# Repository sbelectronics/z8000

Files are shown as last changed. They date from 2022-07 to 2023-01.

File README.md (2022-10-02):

Scott's Z-8000 CP/M-8000 "clover computer"
http://www.smbaker.com/

Description

This is a set of boards that can be assembled to make Z8000 computer,
running the CP/M-8000 distribution. For a detailed writeup, see my
website at http://www.smbaker/com/

Prequisites

* z8kgcc
* cpmtools

Building

Run `make asm` and then `make rom`.

Ports

* 00-0F - SCC, serial I/O
* 10-1F - PIO, parallel I/O
* 20-2F - IDE, compactflash
* 30-3F - unused, optional second IDE
* 40-4F - floppy controller
* 50-53 - display board
* 58-59 - speech synthesizer
* 61-6F - TMS9918 (61 = DATA, 63=CMD, 65-ACR)

Acknowledgements:

* Digital Corporation, CP/M-8k Source Code
* 4sun5bu, Z8001 MB Project including BIOS and Monitor, https://github.com/4sun5bu/Z8001MB

License
* MIT, unless specified elsewhere

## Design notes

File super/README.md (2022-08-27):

# Supervisor board for Z8000
Scott Baker, www.smbaker.com

This directory supports a raspberry pi supervisor. The supervisor can be used
to peek and poke memory locations as well as to run a disk (called "superdisk").

Surprisingly, the C-extension version (supervisor_direct.py) in and of itself
wasn't much faster than the plain ordinary python version. What did really help
was two things: 1) snooping the data bus to look for a wakeup rather than
periodically reading a memory address, and 2) getting rid of as much i2c as
possible in favor of using data buffers.

Speeding up the i2c from 100KHz to 1.2MHz will make a large difference.

to increase i2c speed, edit /boot/config.txt
  dtparam=i2c_arm=on -->  dtparam=i2c_arm=on,i2c_arm_baudrate=1200000

make sure to run raspi-config and disable spi
  otherwise, it'll pull GPIO11 down during start

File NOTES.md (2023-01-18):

Notes

CP/M Headers
  EE00 - nonsegmented, nonexecutable
  EE01 - segmented, executable
  EE02 - nonsegmented, nonexecutable
  EE03 - nonsegmented, executable, nonshared I & D
  EE07 - nonsegmented, executable, shared I & D
  EE0B - nonsegmented, executable, split I & D

Debugging the problem with commands not loading
  stat, zcc, pip, ddt - all EE03 type
  zcc1, zcc2, zcc3, sizez8k, ed - all EE0B type

  sizez8k.z8k (file size 16256)
    EE 0B - nonsegmented, executable, split I & D
    00 04 - four entries in segment table
    00 00 38 4C - 14412 code constant and init
    00 00 00 00 - byte count of relocation data
    00 00 06 6C - 1644 length of symbol table

    # Segment info
    00 03 33 5A - Seg 00, Code, 13146 bytes
    01 04 01 E2 - Seg 01, Constant pool, 482 bytes
    02 05 03 10 - Seg 02, Initialized data, 784 bytes
    03 01 0B 9E - Seg 03, Uninitialized data, 2574 bytes

  zcc2.z8k (file size 65920)
    EE 0B - nonsegmented, executable, split I & D
    00 04 - four entries in segment table
    00 00 EB 4E - 60238 code constant and init
    00 00 00 00 - byte count of relocation data
    00 00 15 30 - 5424 length of symbol table

    # segment info
    00 03 d2 3e - Seg 00, code, 53822 bytes
    01 04 0b d4 - Seg 01, Constant pool, 3026 bytes
    02 05 0d 3c - Seg 02, Initialized data, 3389 bytes
    03 01 35 3e - Seg 03, Uninitialized data, 13630 bytes

  tl/dr: my map_prog file was incorrect, and didn't load instr to the right shadow seg

Tools
  * ZCC - command line interpreter for C
  * ZCC1 - preprocessor
  * ZCC2 - parser
  * ZCC3 - code generator

Customization notes:
  * define a new memtbl in bioscall4.s
  * update map_prog in biosmem.s
  * define new disk parameter blocks in bioscall3.s
  * implement new disk read/write funcs in bioscall3.s

Useful links:
  * http://www.gaby.de/cpm/manuals/archive/cpm22htm/ch6.htm

Boot sequence
  1) Read FCW from 0002
  2) Read PCSEG from 0004
  3) Read PCOFS from 0006

Bios notes
    * Function in R3
    * Parameters in RR4, RR6
    * RR6 return value
        * RL7 = byte
        * R7 = word
        * RR6 = longword
    * Must preserve R8 through R15; most BIOS preserve all but RR6

BIOS Func 9 - Select Disk
    * R5 = disk number
    * return RR6 = 00000000 if nonexistent, DPB addr if exists

BIOS Func 12 - Set DMA Addr
    * RR4 = DMA Address. Note this could be odd or even!!

BIOS Func 13 - read sector
    * return R7=0 on success, 1 on error

BIOS Func 14 - write sector
    * R5 = 0=norma, 1=dir, 2=newblock
    * return R7=0 on success, 1 on error

BIOS Func 21 - flush buffers
    * Return R7=0000 on success, R7=FFFF on error

Memtbl is described in the systemGuide
    * Reg 1 = merged program and data
    * Reg 2 = I for split I/D
    * Reg 3 = D for split I/D
    * Reg 4 = Data access to R2's I segment

SCC external clock
    WR11 D7=0   ; 0 = not a crystal oscillator
    WR14 D1=0   ; use RTxC rather than PCLK

Compile Stuff
  zcc -c -m hello.c
  a:ld8k -w -s -o hello.z8k hello.o -lcpm

  zcc -c -m wump.c
  a:ld8k -w -s -o wump.z8k wump.o startup.o -lcpm

Resources for the basic interpreter project
  * http://www.nicholson.com/rhn/basic/basic.info.html

On making bios calls via bdos
  PUTBOO.C has some good examples
  need to call map_addr a lot
    CDATA = 0
    see syscal.z8k
  ibp.p1 = RR4

  physibp = map_adr( (long) &ibp, CDATA );

  _sel_disk(dsknum);

  ibp.req = SETTRK;
  ibp.p1 = (long) n; // track number
  _bios_call( physibp );

  ibp.req = SETSEC;
  ibp.p1 = (long) n;  // sec number
  _bios_call( physibp );

  ibp.req = BSETDMA;
  ibp.p1 = map_addr((long) addr, CDATA);
  _bios_call( physibp );

  ibp.req = WSECTOR;
  ibp.p1 = DIRSEC;
  _bios_call( physibp );
  
Compiling things and see the assembly output
  zcc -s calltest.c

Trap Handling:
  page 240 of z80 technical manual
  saved on stack:
    PC Offset
    PC Segment (some confusion as it says segment is saved for z8002 but not z8001)
    FCW
    I/T identifier (reason)

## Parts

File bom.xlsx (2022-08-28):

Symbol | Qty | Part Number | Description
(common)
 | many |  | Female double-row 2x40 right angle headers (cur to size)
 | many |  | Male double-row 2x40 right-angle headers (cut to size)
 | many |  | IC sockets, 14-pin, 16-pin, 20-pin, 24-pin, 32-pin, 40-pin, 48-pin, and some 32-ZIFs
 | many | 0.1uf | 0.1uF 2.54mm monolithic ceramics
 | many |  | straight 2.54mm dupont-style headers (cut to size)
 | many |  | right-angle 2.54mm dupont-style headers (cut to size)
(cpu board)
U$1 | 1 | Z0800110PSC | Z8001 CPU
U$2, U$3 | 2 | ATF22V10C | Programmable logic device (must program yourself)
U$4 | 1 | MAX811MEUS+T | reset circuit, 4.38V threshold
U$5 | 1 |  | right-angle button
IC1, IC2, IC7 | 3 | 74HCT373 | Latch
IC3, IC4 | 2 | 74HCT245 | Data Buffer
IC5 | 1 | 74HCT112 | Flip-Flop
IC6 | 1 | 74HCT04 | Hex Inverter
QG1 | 1 |  | 7.3728 MHz oscillator, or 10 MHz oscillator
R1 | 1 | 10K | 10K Resistor
RN3 | 1 | 10K-10 | 10K 11-pin SIP resistor
J4 | 1 |  | barrel jack, for DC-in
C12 | 1 | 100uF | 100uF electrolytic, around 10V
(mem board)
U$1, U$5 | 2 | AS6C4008 | 512Kx8 static RAM
U$2, U$3 | 2 | 39SF040 | 512Kx8 flash IC (must program yourself)
U$6 | 1 | Z0853008PSC | Z8530 SCC
IC3 | 1 | MAX202 | (optional) serial driver, from reputable supplier
J3 | 1 | DB9_Female | (optional) DB9 female
C16 | 1 | 100uF | 100uF electrolytic, around 10V
(display board)
DIS1-DIS8 | 8 | TIL311A | TIL311A or HIL311A displays, from ebay. Spendy.
IC1 | 1 | 74HCT138N | 3-8 decoder
IC2 | 1 | 74HCT688 | logic comparator
IC4 | 1 | 74HCT32
IC5, IC6 | 2 | 74HCT245 | data buffer
RN1, RN2 | 2 | 10K-8 | 10K 9-pin SIP resistor
S1,S2 | 2 |  | 8-position dip switch
J1 | 1 |  | (optional) barrel jack, DC-in for displays
C16 | 1 | 100uF | 100uF electrolytic capacitor, around 10V
(disk board)
U$2 | 1 | WD37C65C | (optional) floppy controller
QG1 | 1 | 16MHz | (optional) 16MHz oscillator
RN1 | 1 | 10K-5 | 10K 6-pin SIP resistor
IC1, IC2 | 2 | 74HCT245 | Data Buffer
IC3 | 1 | ATF16V8B | Programmable logic device (must program yourself)
CON2 | 1 | N7E50-7516PK-20 | compactflash socket
R1, R2, R3, R6, R7 | 5 | 1K | 1K resistor
R4 | 1 | 5.6K | 5.6K resistor
R5 | 1 | 10K | 10K resistor
C16 | 1 | 100uF | 100uF electrolytic, around 10V

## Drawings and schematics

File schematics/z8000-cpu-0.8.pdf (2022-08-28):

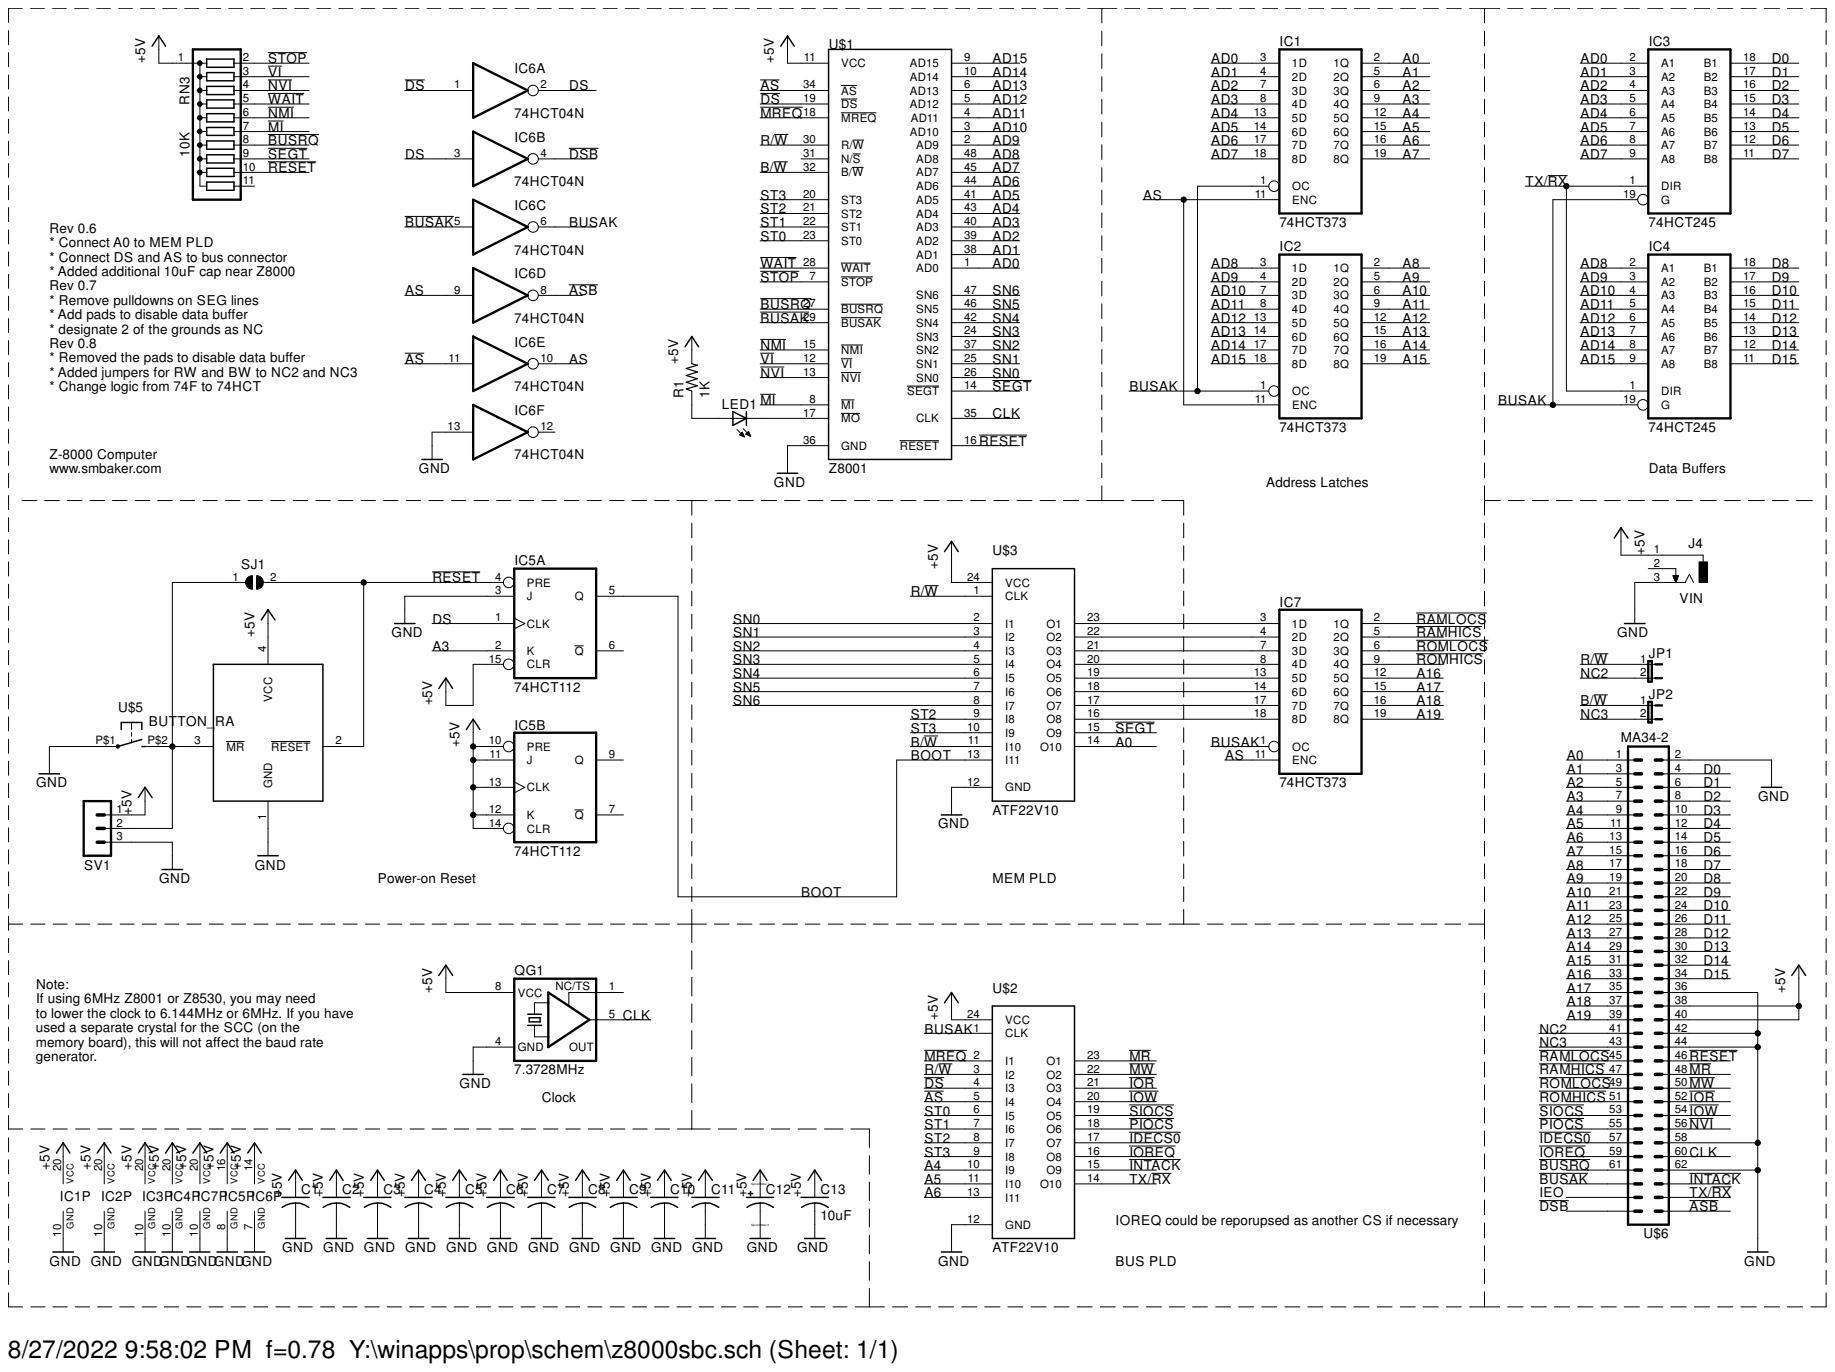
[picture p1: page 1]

Rev 0.6
* Connect A0 to MEM PLD
* Connect DS and AS to bus connector
* Added additional 10uF cap near Z8000
Rev 0.7
* Remove pulldowns on SEG lines
* Add pads to disable data buffer
* designate 2 of the grounds as NC
Rev 0.8
* Removed the pads to disable data buffer
* Added jumpers for RW and BW to NC2 and NC3

* Change logic from 74F to 74HCT

Note:
If using 6MHz Z8001 or Z8530, you may need
to lower the clock to 6.144MHz or 6MHz. If you have
used a separate crystal for the SCC (on the
memory board), this will not affect the baud rate
generator.

IOREQ could be reporupsed as another CS if necessary

8/27/2022 9:58:02 PM f=0.78 Y:\winapps\prop\schem\z8000sbc.sch (Sheet: 1/1)

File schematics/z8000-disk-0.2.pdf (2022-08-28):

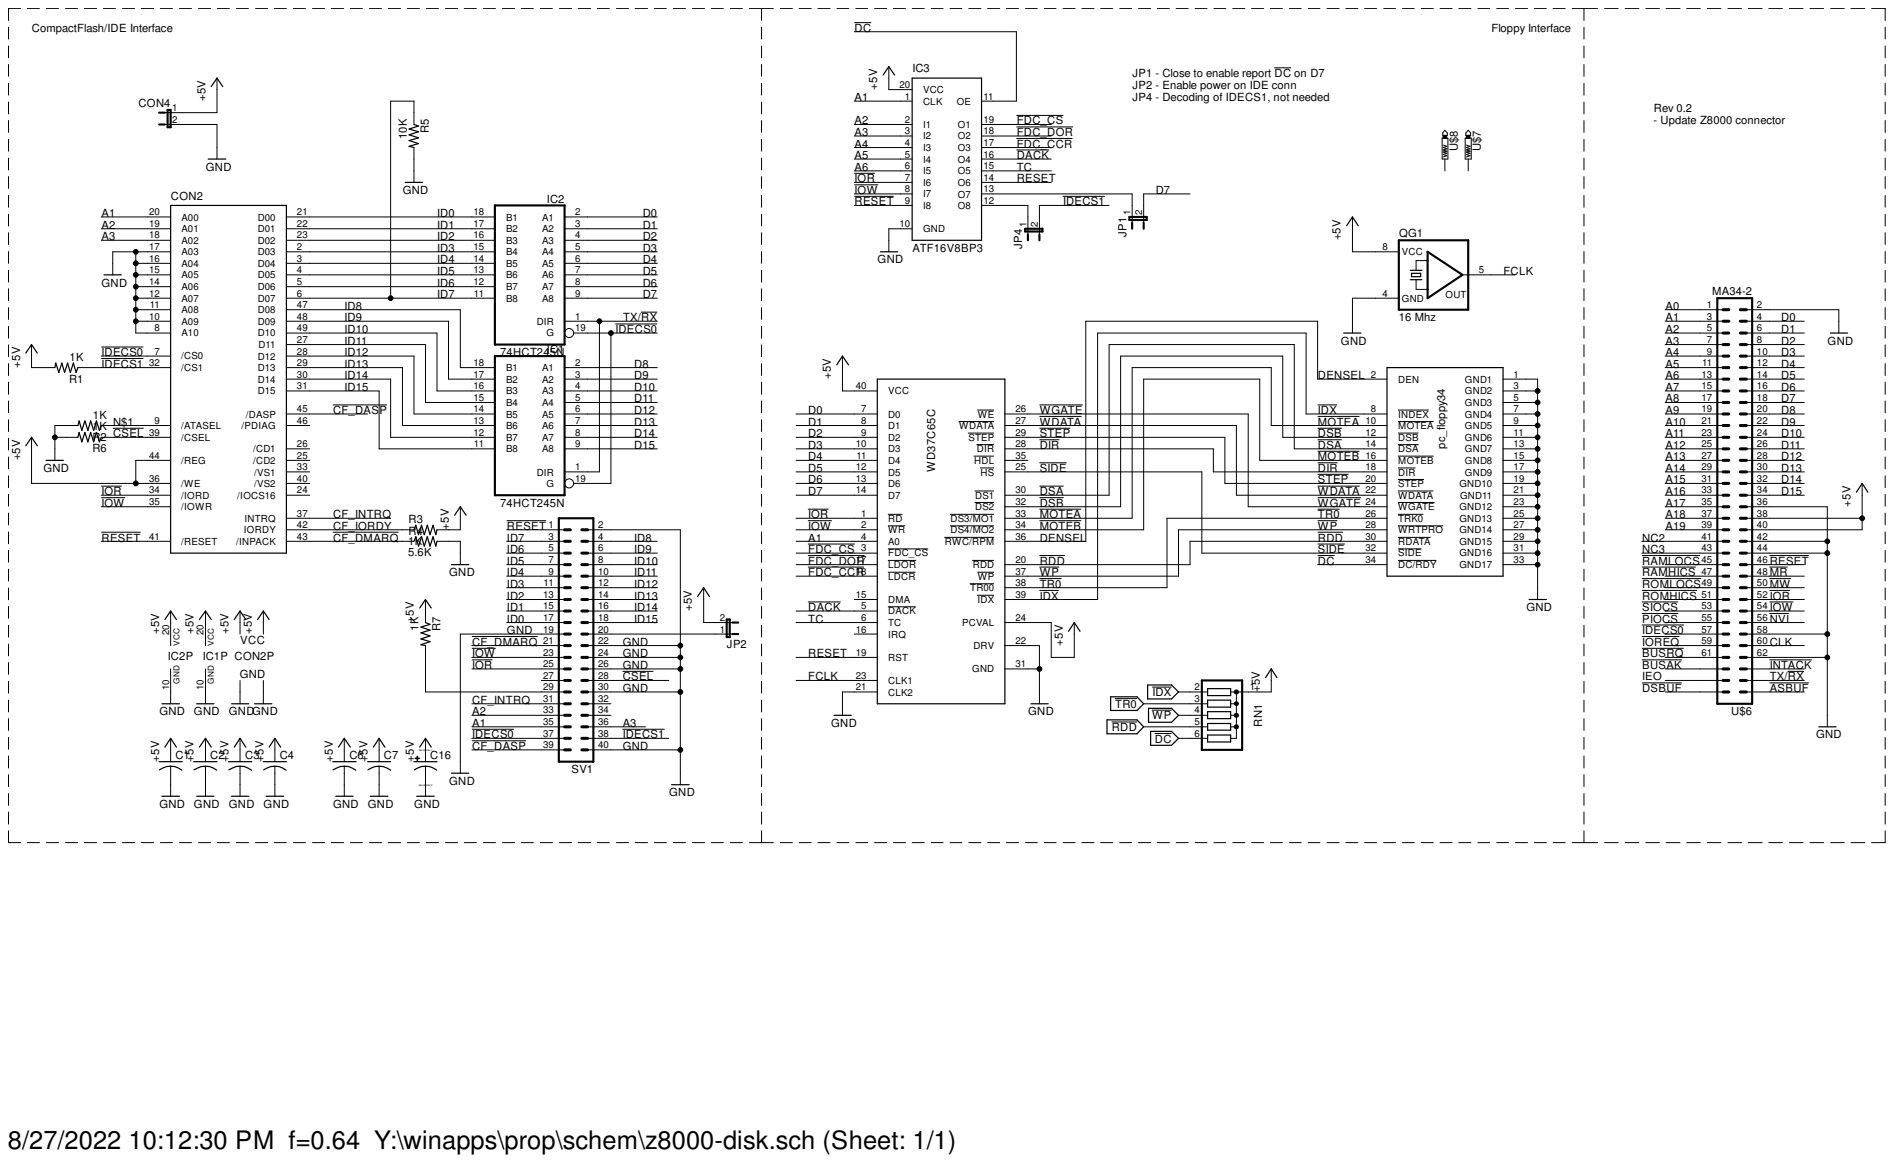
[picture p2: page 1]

JP1 - Close to enable report DC on D7
JP2 - Enable power on IDE conn
JP4 - Decoding of IDECS1, not needed

A07 12 | | ID7
A08 11 | ID8
A09 10 | ID9
A10 8 | ID10
/CS0 7 /CS1 32 /ATASEL 9 /CSEL 39 /REG 44 | ID11

8/27/2022 10:12:30 PM f=0.64 Y:\winapps\prop\schem\z8000-disk.sch (Sheet: 1/1)

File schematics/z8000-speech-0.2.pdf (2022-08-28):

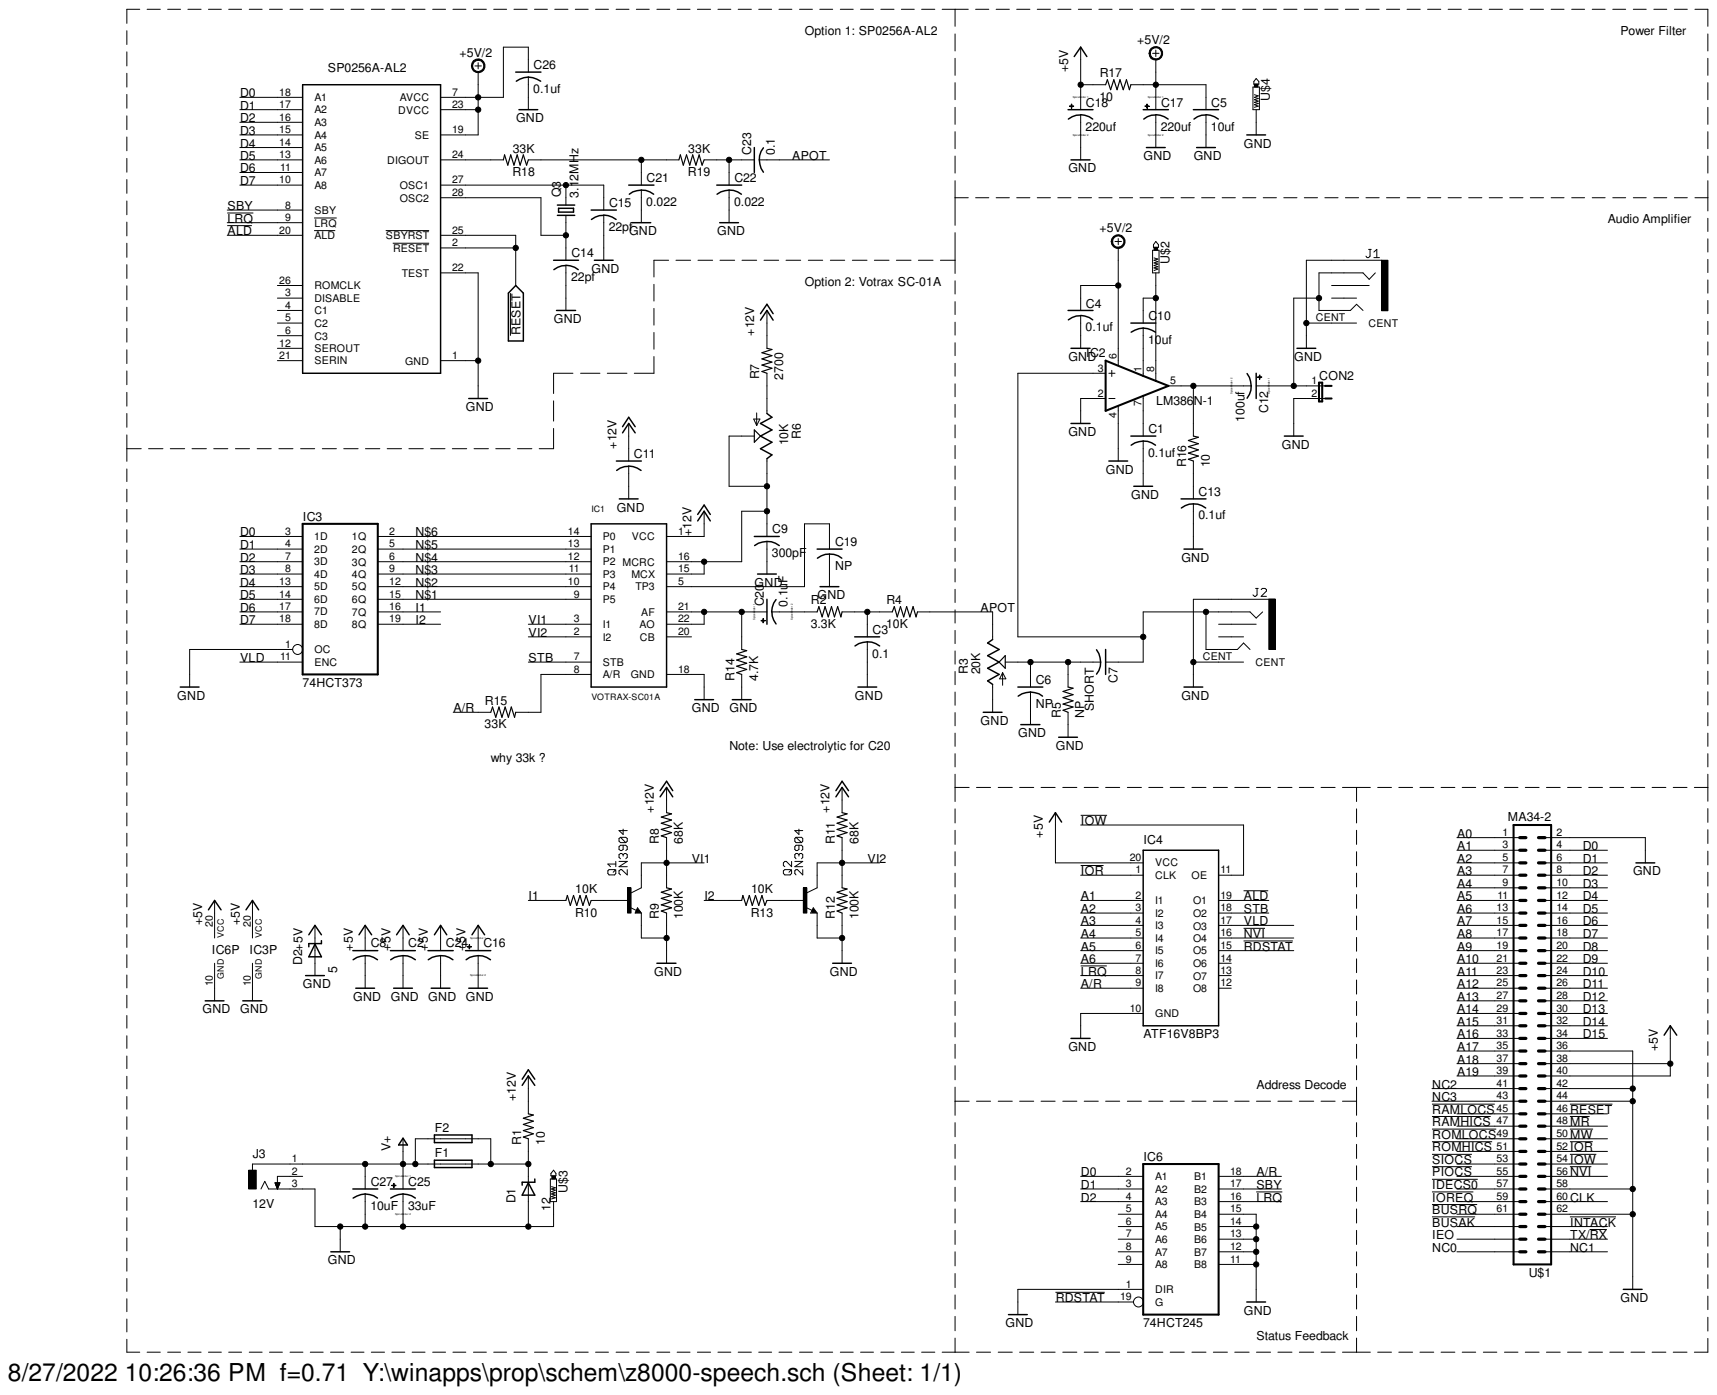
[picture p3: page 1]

Note: Use electrolytic for C20

8/27/2022 10:26:36 PM f=0.71 Y:\winapps\prop\schem\z8000-speech.sch (Sheet: 1/1)

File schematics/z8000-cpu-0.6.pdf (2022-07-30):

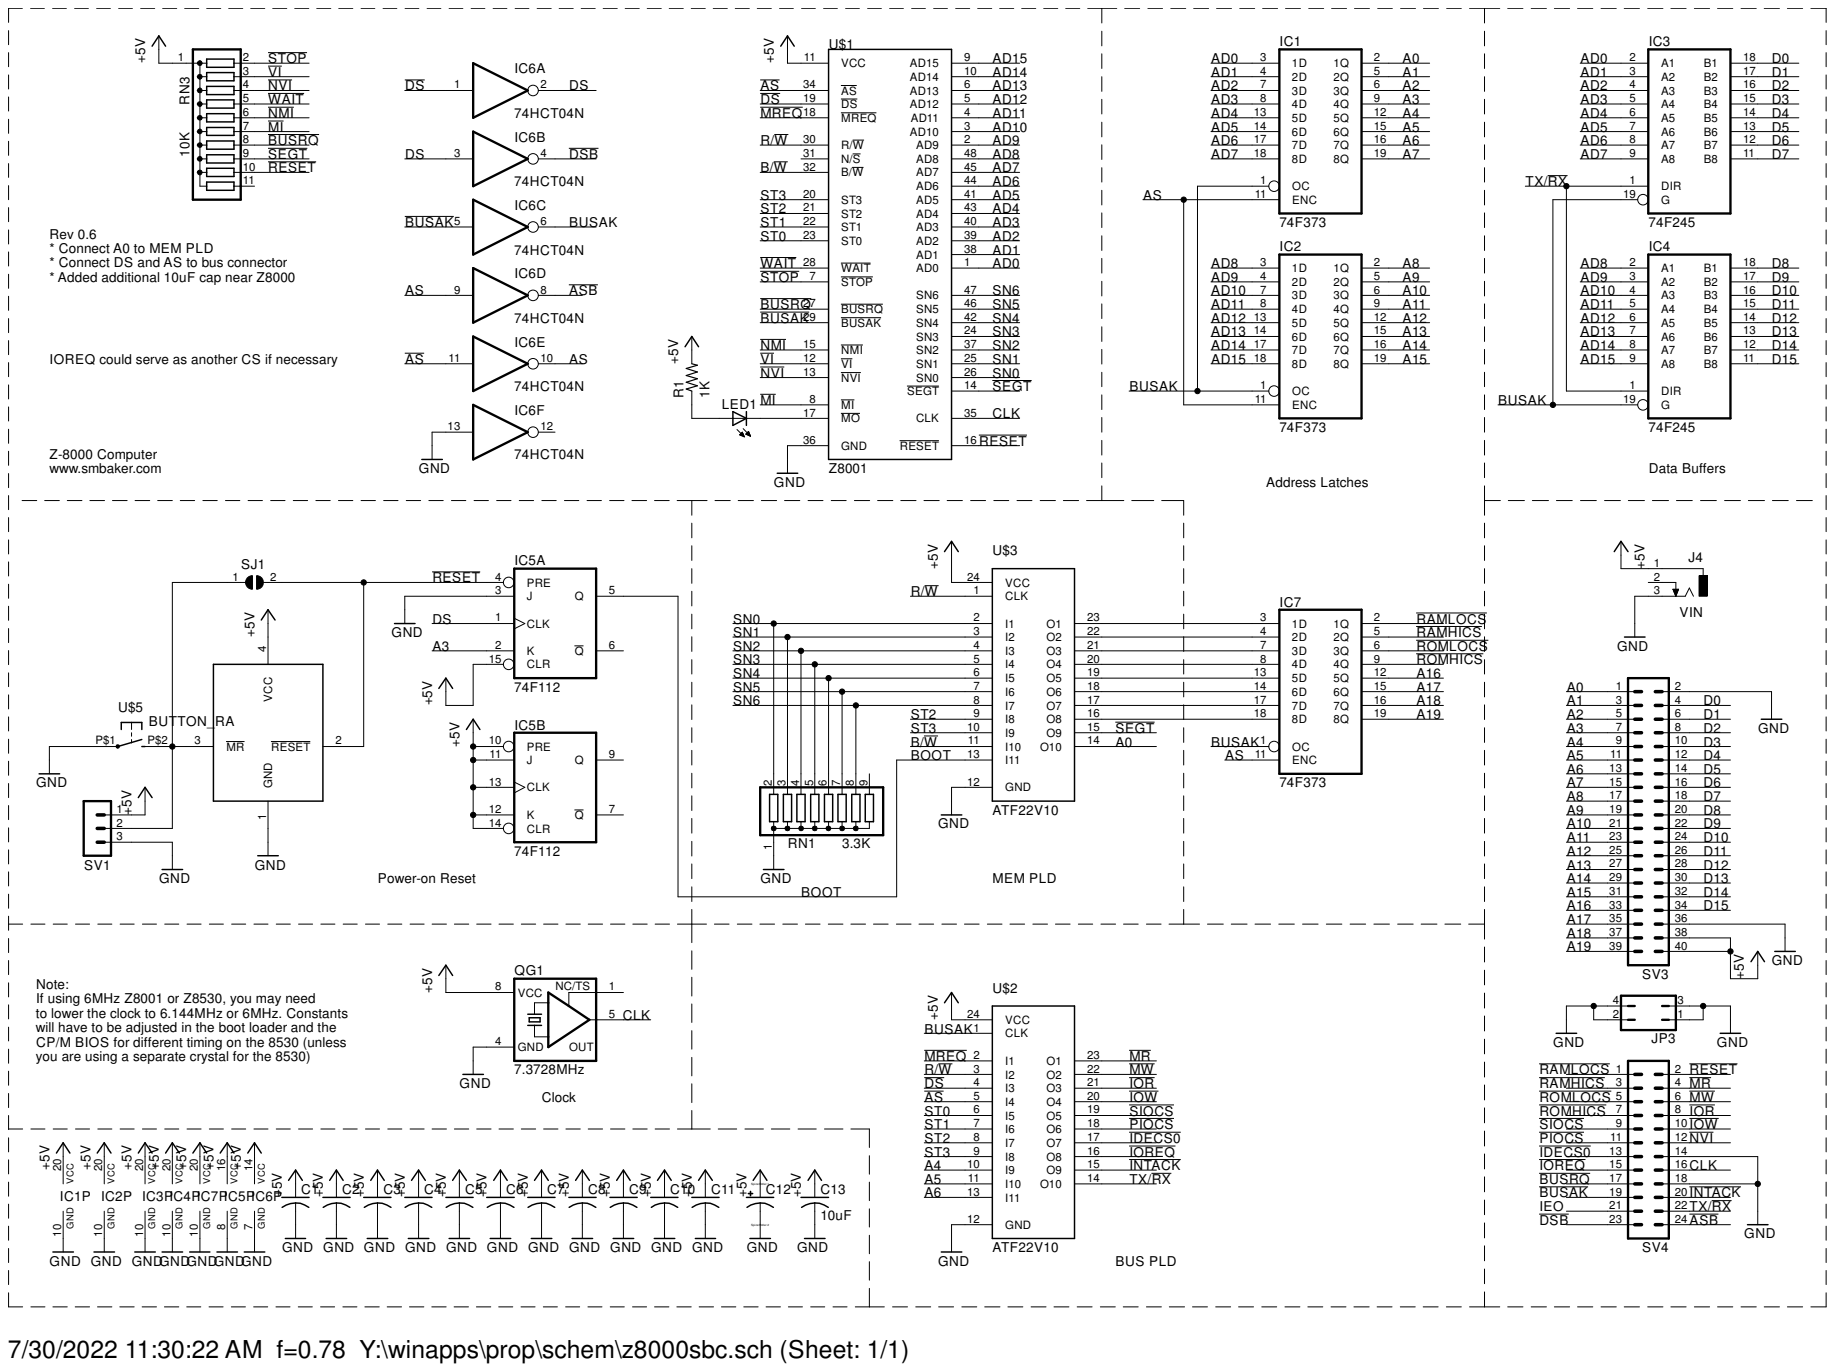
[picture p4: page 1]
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

IOREQ could serve as another CS if necessary

Note:
If using 6MHz Z8001 or Z8530, you may need
to lower the clock to 6.144MHz or 6MHz. Constants
will have to be adjusted in the boot loader and the
CP/M BIOS for different timing on the 8530 (unless
you are using a separate crystal for the 8530)

7/30/2022 11:30:22 AM f=0.78 Y:\winapps\prop\schem\z8000sbc.sch (Sheet: 1/1)

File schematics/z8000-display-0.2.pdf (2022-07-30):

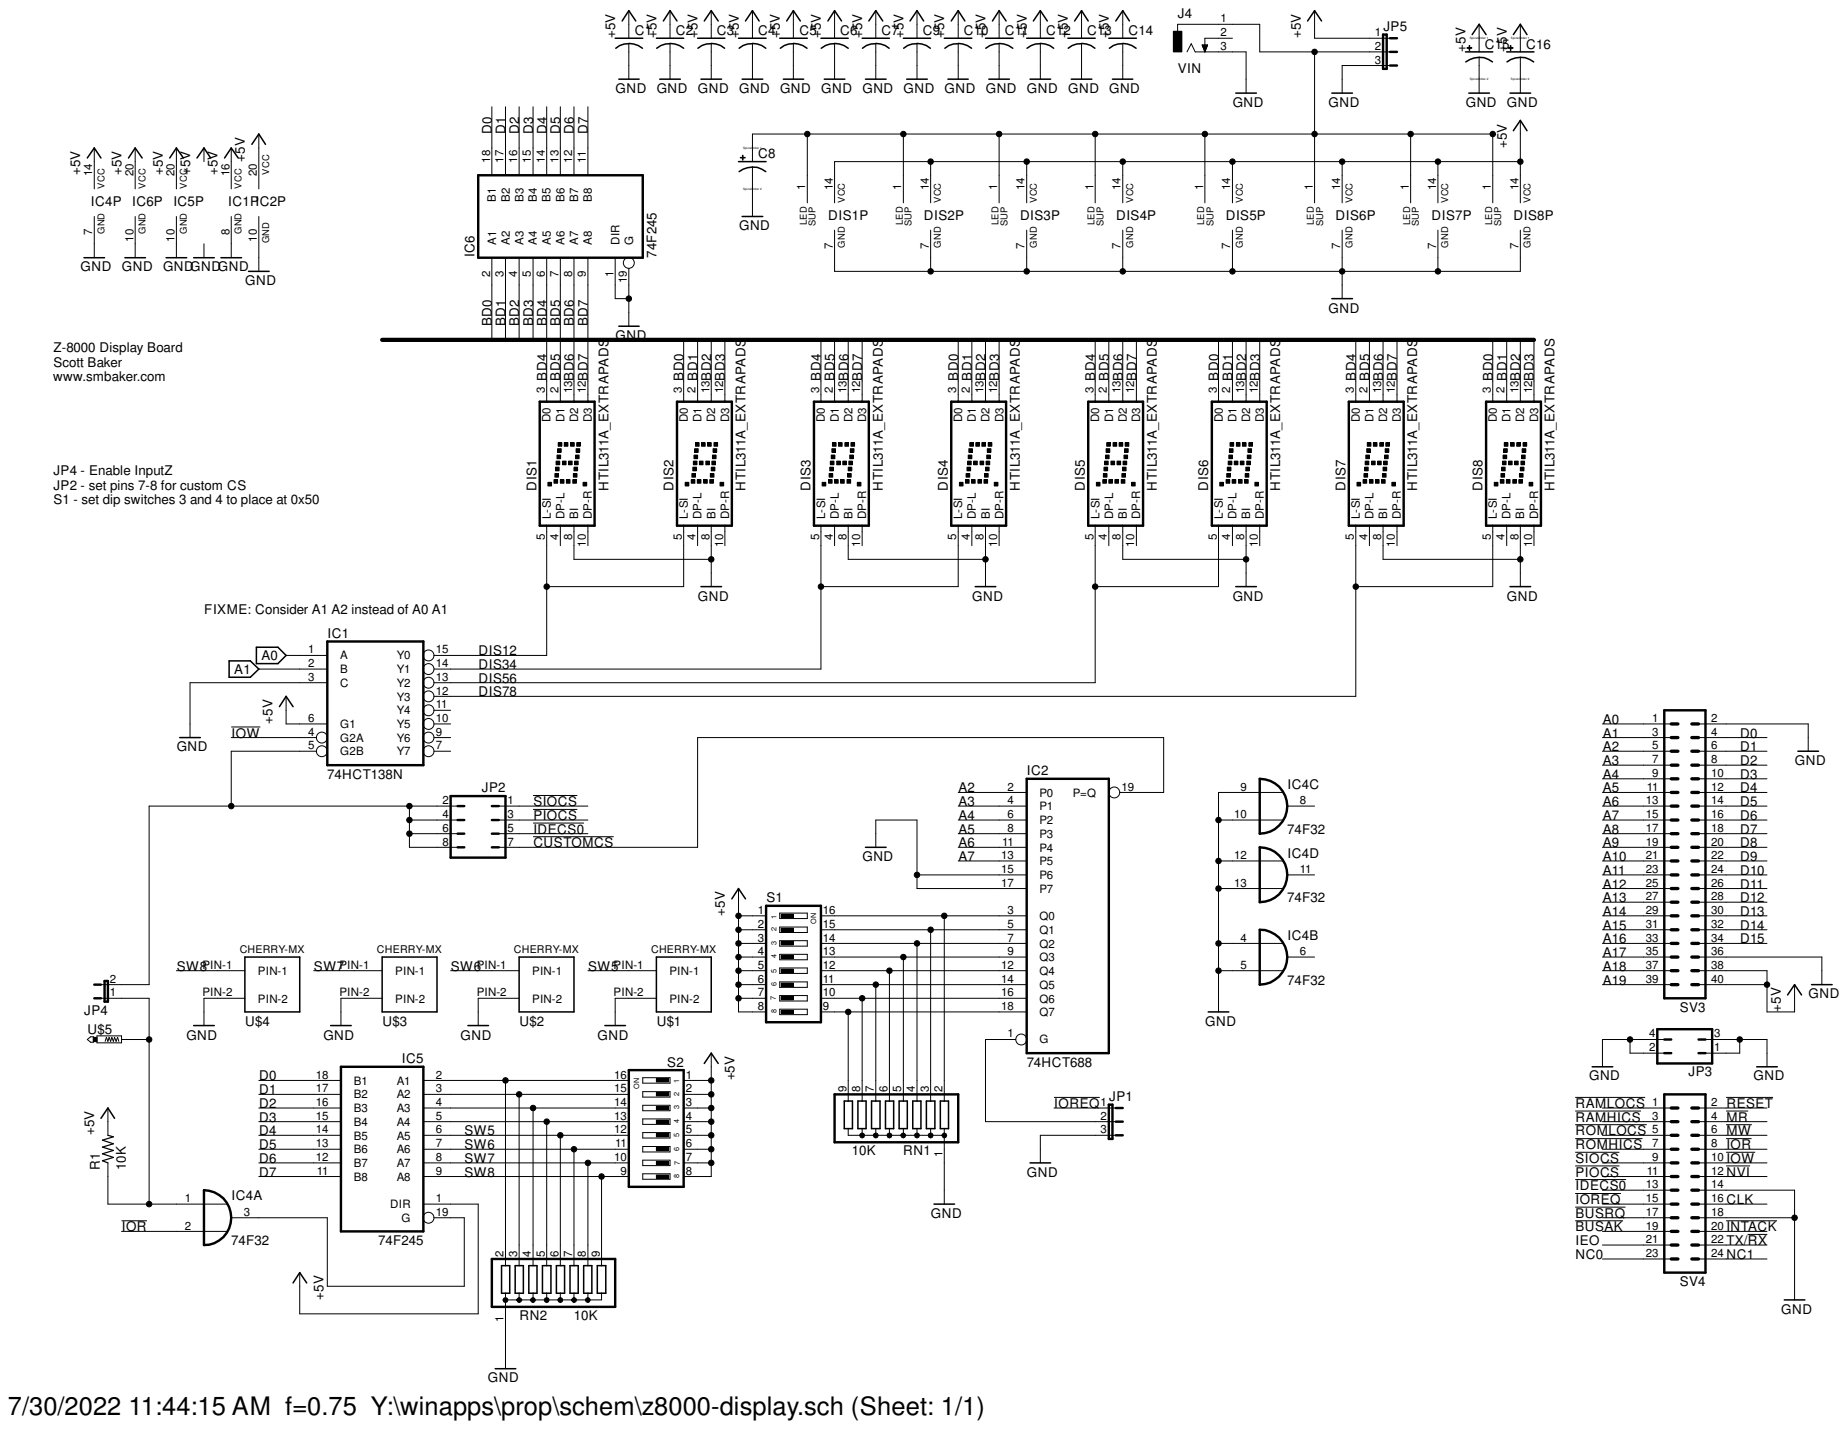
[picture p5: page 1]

JP4 - Enable InputZ
JP2 - set pins 7-8 for custom CS
S1 - set dip switches 3 and 4 to place at 0x50

FIXME: Consider A1 A2 instead of A0 A1

7/30/2022 11:44:15 AM f=0.75 Y:\winapps\prop\schem\z8000-display.sch (Sheet: 1/1)

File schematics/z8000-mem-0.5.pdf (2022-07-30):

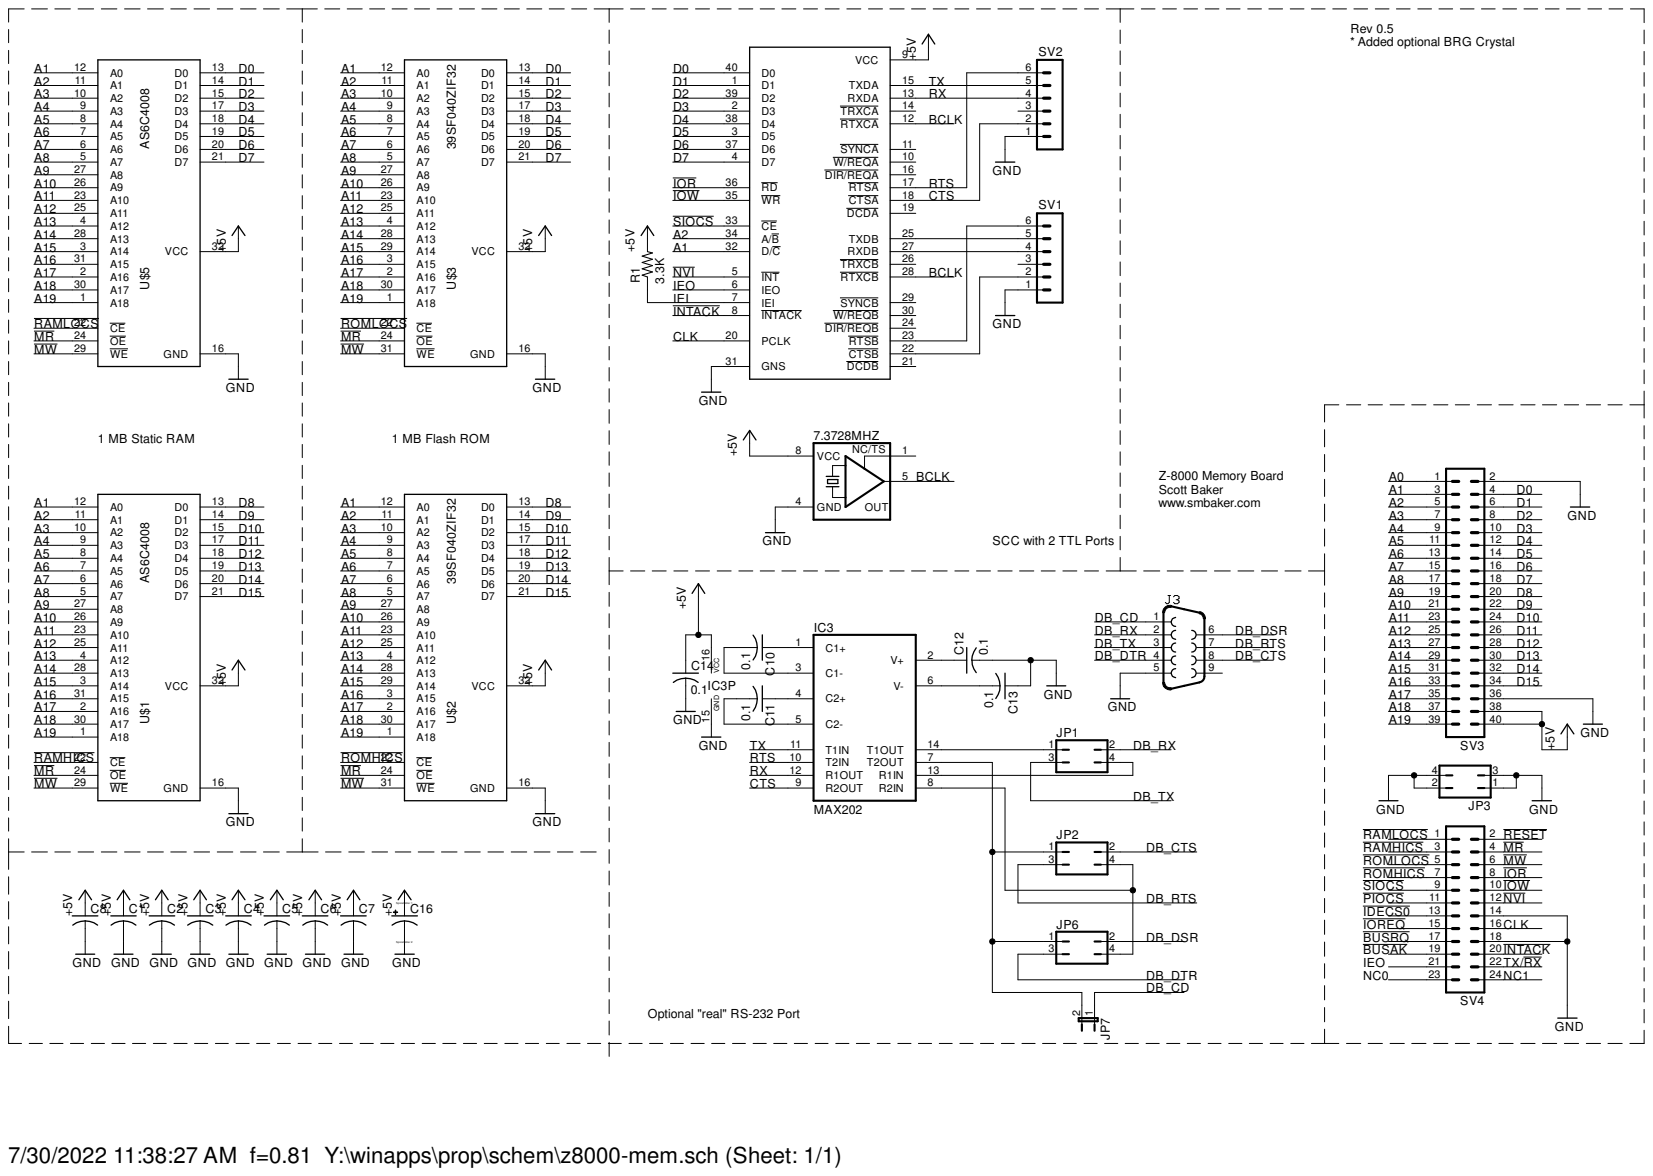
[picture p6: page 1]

Rev 0.5
* Added optional BRG Crystal

SCC with 2 TTL Ports

Optional "real" RS-232 Port

7/30/2022 11:38:27 AM f=0.81 Y:\winapps\prop\schem\z8000-mem.sch (Sheet: 1/1)

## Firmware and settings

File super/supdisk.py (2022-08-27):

from __future__ import print_function
from supervisor_direct import SupervisorDirect

import os
import smbus
import string
import sys
import time
from optparse import OptionParser

CMD_OFS = 0
ADDR_OFS = 2
DMA_OFS = 6

CMD_INIT = 0
CMD_READ = 1
CMD_WRITE = 2

class SuperDisk(SupervisorDirect):
    def __init__(self, verbose, stats):
        SupervisorDirect.__init__(self, verbose)
        self.superAddress = self.find_super()

        self.filename = "sup.img"
        self.f = None
        self.mtime = 0
        self.wokeCount = 0
        self.fallCount = 0
        self.falseCount = 0
        self.elap = 0.0
        self.elapCount = 0.0
        self.stats = stats

    def check_open(self):
        if self.f is not None:
            mtime = os.stat(self.filename).st_mtime
            if (mtime > self.mtime):
                print("possible file change detected")
                self.f.close()
                self.f=None
        if self.f is None:
            self.f = open("sup.img", "r+b")
            self.mtime = os.stat(self.filename).st_mtime


    """ implemented in C now... """
    def wait_for_signal(self):
        hit1=False
        hit2=False
        tStart = time.time()
        while True:
            m = self.ext.mem_snoop()
            if m == 0x73E7:
                hit1=True
            if m == 0xF912:
                hit2=True
            if hit1 and hit2:
                return True
            if (time.time()-tStart) > 0.1:
                return False

    def account(self, woke, cmd, tStart):
        if (cmd == 0):
            if woke:
                self.falseCount += 1
            else:
                # not woke, no command == idle
                return
        else:
            if woke:
                self.wokeCount += 1
            else:
                self.fallCount += 1
        
        if ((self.wokeCount + self.fallCount + self.falseCount) % 100) == 0:
            if self.elapCount > 0:
                elapsed = (self.elap/self.elapCount)
            else:
                elapsed = 0

            if self.verbose or self.stats:
                print("woke %d, fall %d, false %d, avg %0.4f" % (self.wokeCount, self.fallCount, self.falseCount, elapsed))

        if (tStart is not None) and (cmd in [1,2]):
            self.elap = self.elap + time.time() - tStart
            self.elapCount += 1

        if self.verbose:
            if tStart is not None:
                print(time.time() - tStart)

    def run(self):
        lastWoke = False
        while True:
            (cmd, fileAddr, dmaAddr) = self.get_cmd()
            if cmd == CMD_READ:
                tStart = time.time()
                self.read(fileAddr, dmaAddr)
                self.account(lastWoke, cmd, tStart)
            elif cmd == CMD_WRITE:
                tStart = time.time()                
                self.write(fileAddr, dmaAddr)
                self.account(lastWoke, cmd, tStart)
            elif cmd == CMD_INIT:
                print("set-active")
                self.set_active()
            else:
                self.account(lastWoke, 0, None)

            lastWoke = self.ext.wait_signal();

    def mapseg(self, x):
        # We will get called with segment numbers, which
        # we need to map to disk addresses. Do the same
        # thing the Memory PLD does.

        segmap = {0x10: 0x08,    # separate I/D as D
                  0x11: 0x09,
                  0x12: 0x0A,
                  0x13: 0x0B,
                  0x14: 0x0C,
                  0x15: 0x0D,
                  0x16: 0x0E,
                  0x17: 0x0F,

                  0x18: 0x00,    # I-as-D shadows
                  0x19: 0x01,
                  0x1A: 0x02,
                  0x1B: 0x03,
                  0x1C: 0x04,
                  0x1D: 0x05,
                  0x1E: 0x06,
                  0x1F: 0x07}
        seg = x >> 24
        seg = segmap.get(seg, seg)

        return (x&0x00FFFFFF | (seg << 24))

    def read(self, fileAddr, dmaAddr):
        if (not self.is_taken()):
            print("read while bus not taken");
            sys.exit(-1)

        dmaAddr = self.mapseg(dmaAddr)
        if self.verbose:      
            print("read %X %X\n" %(fileAddr, dmaAddr))

        if (dmaAddr & 1) != 0:
            print("unaligned read %X\n" % dmaAddr)
            sys.exit(-1)

        try:
            #self.take_bus()

            self.check_open()

            self.f.seek(fileAddr*128)
            buf = self.f.read(128)
            hi = True
            addr = dmaAddr
            self.mem_write_start(addr)
            self.mem_write_buffer(addr, buf)            
            self.mem_write_end()

            if self.verbose:
              print("sent %d" % (addr-self.superAddress-BUF_OFS))

            # Let CPM-8K know we're done
            self.mem_write(self.superAddress + CMD_OFS, 0x81)
        finally:
            self.release_bus()

    def write(self, fileAddr, dmaAddr):
        if (not self.is_taken()):
            print("write while bus not taken");
            sys.exit(-1)

        dmaAddr = self.mapseg(dmaAddr)
        if self.verbose:     
            print("write %X %X\n" %(fileAddr, dmaAddr))

        if (dmaAddr & 1) != 0:
            print("unaligned write %X\n" % dmaAddr)
            sys.exit(-1)

        try:
            #self.take_bus()

            self.check_open()

            buf = bytearray(128)
            addr = dmaAddr
            self.mem_read_start(addr)
            for i in range(0,64):
                w = self.mem_read_fast(addr)
                buf[i*2] = w>>8
                buf[i*2+1] = w & 0xFF
                addr += 2
            self.mem_read_end()

            if self.verbose:
              print("received %d" % (addr-self.superAddress-BUF_OFS))

            self.f.seek(fileAddr*128)
            self.f.write(buf)

            # don't detect our own change
            self.mtime = os.stat(self.filename).st_mtime + 2

            # Let CPM-8K know we're done
            self.mem_write(self.superAddress + CMD_OFS, 0x82)
        finally:
            self.release_bus()            

    def get_cmd(self):
        keep_bus = False
        try:
            self.take_bus()
            self.mem_read_start(self.superAddress)
            cmd = self.mem_read_fast(self.superAddress + CMD_OFS)
            fileAddr = None
            dmaAddr = None
            if (cmd==1) or (cmd==2):
                fileAddr = (self.mem_read_fast(self.superAddress + ADDR_OFS) << 16) | \
                            self.mem_read_fast(self.superAddress + ADDR_OFS+2)
                dmaAddr  = (self.mem_read_fast(self.superAddress + DMA_OFS) << 16) | \
                            self.mem_read_fast(self.superAddress + DMA_OFS+2)
                dmaAddr = dmaAddr & 0x7FFFFFFF
                # keep the bus for now. We're about to call _read or _write. They can release
                # the bus.
                keep_bus = True
            return (cmd, fileAddr, dmaAddr)
        finally:
            if (not keep_bus):
                self.release_bus()

    def set_active(self):
        try:
            self.take_bus()
            self.mem_write(self.superAddress + CMD_OFS, 0x80)
        finally:
            self.release_bus()

    def find_super(self):
        v2 = 0
        v3 = 0
        v4 = 0
        try:
            self.take_bus()
            base = 0x030057A0  # start close to where we think it will be
            self.mem_read_start(base)
            while (base < 0x0300FFFF):
                v = self.mem_read_fast(base)
                if (v4 == 0x73E7) and (v3 == 0xF912) and (v2 == 0xA320) and (v == 0xBB49):
                    return base+2
                v4 = v3
                v3 = v2
                v2 = v
                base += 2
        finally:
            self.mem_read_end()
            self.release_bus()
        return None


def main():
    parser = OptionParser(usage="supervisor [options] command",
                          description="Commands: ...")

    parser.add_option("-v", "--verbose", dest="verbose",
         help="verbose", action="store_true", default=False)
    parser.add_option("-s", "--stats", dest="stats",
         help="stats", action="store_true", default=False)
    parser.add_option("-f", "--filename", dest="filename",
         help="filename", default=None)
    parser.add_option("-n", "--norelease", dest="norelease",
         help="do not release bus", action="store_true", default=False)

    (options, args) = parser.parse_args(sys.argv[1:])

    super = SuperDisk(options.verbose, options.stats)

    if super.superAddress == None:
        print("Super not found in memory")
        sys.exit(-1)
    print("Super found at %08X" % super.superAddress)

    super.run()


if __name__=="__main__":
    main()

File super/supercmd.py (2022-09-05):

from __future__ import print_function
import smbus
import string
import sys
import time
from smbpi.ioexpand import *
from optparse import OptionParser
#from hexfile import HexFile

from supervisor import Supervisor
from supervisor_direct import SupervisorDirect

def hex_escape(s):
    printable = string.ascii_letters + string.digits + string.punctuation + ' '
    return ''.join(c if c in printable else r'\x{0:02x}'.format(ord(c)) for c in s)

def load_image(super, fn):
    addr = 0x03000000
    super.mem_write_start(addr)    
    try:
        word = 0
        odd = False
        filebytes = open(fn, "rb").read()
        for b in filebytes:
            if odd:
                word = (word << 8) | b
                super.mem_write_fast(addr, word)
                addr += 2
                odd = False
            else:
                odd = True
                word = b
    finally:
        super.mem_write_end()

def save_image(super, fn):
    addr = 0x03000000
    super.mem_read_start(addr)    
    try:
        f = open(fn, "wb")
        for i in range(0, 32768):
            word = super.mem_read_fast(addr)
            f.write(word.to_bytes(2,"big"))
            addr += 2
    finally:
        super.mem_read_end()        

def main():
    parser = OptionParser(usage="supervisor [options] command",
            description="Commands: ...")

    parser.add_option("-A", "--addr", dest="addr",
         help="address", metavar="ADDR", type="string", default=0)
    parser.add_option("-C", "--count", dest="count",
         help="count", metavar="ADDR", type="int", default=65536)
    parser.add_option("-V", "--value", dest="value",
         help="value", metavar="VAL", type="string", default=0)
    parser.add_option("-P", "--ascii", dest="ascii",
         help="print ascii value", action="store_true", default=False)
    parser.add_option("-R", "--rate", dest="rate",
         help="rate for slow clock", metavar="HERTZ", type="int", default=10)
    parser.add_option("-B", "--bank", dest="bank",
         help="bank number to select on ram-rom board", metavar="NUMBER", type="int", default=None)
    parser.add_option("-v", "--verbose", dest="verbose",
         help="verbose", action="store_true", default=False)
    parser.add_option("-f", "--filename", dest="filename",
         help="filename", default=None)
    parser.add_option("-r", "--reset", dest="reset_on_release",
         help="reset on release of bus", action="store_true", default=False)
    parser.add_option("-n", "--norelease", dest="norelease",
         help="do not release bus", action="store_true", default=False)
    parser.add_option("-i", "--indirect", dest="direct",
         help="use the python supervisor", action="store_false", default=True)

    #parser.disable_interspersed_args()

    (options, args) = parser.parse_args(sys.argv[1:])

    if len(args)==0:
        print("missing command")
        sys.exit(-1)

    cmd = args[0]
    args=args[1:]

    if options.direct:
      print("using direct supervisor")
      super = SupervisorDirect(options.verbose)
    else:
      print("using python supervisor")
      bus = smbus.SMBus(1)
      super = Supervisor(bus, 0x20, options.verbose)
    
    addr = None
    if (options.addr):
        if options.addr.startswith("0x") or options.addr.startswith("0X"):
            addr = int(options.addr[2:], 16)
        elif options.addr.startswith("$"):
            addr = int(options.addr[1:], 16)
        else:
            addr = int(options.addr)

    value = None
    if (options.value):
        if options.value.startswith("0x") or options.value.startswith("0X"):
            value = int(options.value[2:], 16)
        elif options.addr.startswith("$"):
            value = int(options.value[1:], 16)
        else:
            value = int(options.value)            

    if (cmd=="reset"):
        try:
            super.take_bus()
        finally:
            if not options.norelease:
                super.release_bus(reset=True)

    elif (cmd=="memdump"):
        try:
            super.take_bus()
            for i in range(addr,addr+options.count, 2):
                val = super.mem_read(i)
                if options.ascii:
                    print("%04X %04X %s %s" % (i, val, hex_escape(chr(val>>8), hex_escape(chr(val & 0xFF)))))
                else:
                    print("%04X %04X" % (i, val))
        finally:
            if not options.norelease:
                super.release_bus()

    elif (cmd=="peek"):
        try:
            super.take_bus()
            print("%04X" % super.mem_read(addr))
        finally:
            if not options.norelease:
                super.release_bus()

    elif (cmd=="poke"):
        try:
            super.take_bus()
            super.mem_write(addr, value)
        finally:
            if not options.norelease:
                super.release_bus()

    elif (cmd=="showint"):
        last=None
        while True:
            v = ((super.ixData.get_gpio(1)&INT) !=0)
            if v!=last:
                print(v)
                last=v

    elif (cmd=="loadimg"):
        try:
            super.take_bus()
            load_image(super, options.filename)
        finally:
            if not options.norelease:
                super.release_bus(reset=True)

    elif (cmd=="saveimg"):
        try:
            super.take_bus()
            save_image(super, options.filename)
            super.reset()
        finally:
            if not options.norelease:
                super.release_bus()                


if __name__=="__main__":
    main()

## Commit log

2022-08-10 programs for turning the LED on and off
2022-08-14 ledon and ledoff binaries
2022-08-27 check in gerbers
    [z8000-disk.GBL, z8000-disk.GBO, z8000-disk.GBS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]
2022-08-28 check in disk and speech gerbers
2022-08-28 add bill of materials
    [bom.xlsx]
2022-10-02 video board driver and keyboard wip
2022-10-02 video board pld
2022-10-02 speech board plds
2023-01-15 support for h8 board
2023-01-21 disable interrupts inside NVI handler; fix performance issues; reset cio
2023-01-22 switch to or-priority mode
2023-01-22 fcw and ps registers; support cio timer
2023-01-22 display the right frame when in break
